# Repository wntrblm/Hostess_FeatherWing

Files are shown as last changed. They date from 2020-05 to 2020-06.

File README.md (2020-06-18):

# Winterbloom Hostess FeatherWing

Picture of the FeatherWing

**:warning: Hostess is *extremely* experimental at this stage. It is not ready for prime time. I welcome folks who want to help out and poke around, but please do not expect anything here to work or make sense. Please reach out to me at me@thea.codes if you're interesting in helping out.**

Hostess is a [FeatherWing](https://learn.adafruit.com/adafruit-feather/featherwings) that provides a USB host co-processor. The FeatherWing handles all USB Host related tasks, including enumeration **and running the device drivers**, and communicates with the primary processor over [SPI](https://learn.adafruit.com/circuitpython-basics-i2c-and-spi/spi-devices). This means the primary processor can communicate with USB devices with minimal software and CPU time.

For example, a [CircuitPython](https://circuitpython.org)-based board could communicate with a USB MIDI device with minimal code:

```python
_spi = busio.SPI(board.SCK, MOSI=board.MOSI, MISO=board.MISO)
spi = SPIDevice(_spi, digitalio.DigitalInOut(board.D9), phase=1, polarity=0, baudrate=8000000)
hostess_midi_in = HostessMidiPortIn(spi)

while True:
    midi_event = hostess_midi_in.read()

    if midi_event is not None:
        print(midi_event)
```

Presently, Hostess has basic support for the following USB devices:

* MIDI
* Keyboard

And in-progress support for the following devices:

* PS4 controller

And I hope to add support for these devices eventually:

* USB Serial (CDC)
* Generic HID Gamepad
* Mouse

## Hardware

Hostess's [hardware](hardware) is based around the [Atmel SAMD21](https://www.microchip.com/wwwproducts/en/ATsamd21g18), a low-cost 32-bit ARM microcontroller with USB host capabilities. It incorporates a USB current-limiting switch to prevent devices from drawing too much current and provides the proper amount of capacitance for powering USB devices. This makes it a bit more robust compared to using an OTG adapter with existing development boards.

Hostess's hardware is the most complete part of the project. PCBs can be manufactured at OSHPark or other fabs and all of the components on the BOM are readily available at Mouser and DigiKey.

To upload the firmware and debug the device, you'll need a [SOICBite](https://github.com/SimonMerrett/SOICbite) and a J-Link or similar.

## Firmware

Hostess's [firmware](firmware) is written in C using [Atmel START](https://start.atmel.com/). Presently building it requires [Atmel Studio 7](https://www.microchip.com/mplab/avr-support/atmel-studio-7), though I'd like to switch to a Makefile.

## Library

Communicating with Hostess is the most incomplete part of the project. Presently, there is just an [example file](library/circuitpython.py) on how to communicate with it from CircuitPython. I'd like to make this a complete library as well as create an Arduino library.

## License and contributing

The code here is available under the [MIT License](firmware/LICENSE), the hardware designs are available under [CC BY-SA 4.0](hardware/LICENSE). I welcome contributors, please read the [Code of Conduct](CODE_OF_CONDUCT.md) first. :)

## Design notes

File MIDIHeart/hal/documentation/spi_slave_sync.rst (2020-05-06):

The SPI Slave Synchronous Driver
================================

The serial peripheral interface (SPI) is a synchronous serial communication
interface.

SPI devices communicate in full duplex mode using a master-slave
architecture with a single master. The slave device uses the control signal
and clocks from master for reading and writing. Slave device is selected through
slave select (SS) line.

When data is read or written through the I/O writing function, the driver keeps
polling until amount of characters achieved. Also it's possible to perform
full-duplex read and write through transfer function, which process read and
write at the same time.

When SS detection is considered, a "break on SS detection" option can be enabled
to make it possible to terminate the read/write/transfer on SS desertion.

Features
--------

* Initialization/de-initialization
* Enabling/disabling
* Control of the following settings:

  * SPI mode
  * Character size
  * Data order
* Data transfer: transmission, reception and full-duplex

Applications
------------

* SPI to I2C bridge that bridges SPI commands to I2C interface.

Dependencies
------------

SPI slave capable hardware

Concurrency
-----------

N/A

Limitations
-----------

N/A

Known issues and workarounds
----------------------------

When writing data through SPI slave, the time that the data appears on data line
depends on the SPI hardware, and previous writing state, since there can be
data in output fifo filled by previous broken transmitting. The number of such
dummy/broken characters is limited by hardware. Whether these dummy/broken
characters can be flushed is also limited by hardware.

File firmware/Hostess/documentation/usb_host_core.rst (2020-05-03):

=============
USB Host Core
=============

USB Host Core is a part of the USB Host Stack library. It handles the hub
changes and issue necessary requests during USB Enumeration process, selects
and installs right class driver to bring up connected devices.
For more detailed description about Bus Enumeration, user can refer to
Chapter 9 (USB Host Framework) in Universal Serial Bus Specification.

The core stack driver is designed to simplify the enumeration of USB device.
After initialization, function drivers can be registered to make corresponding
USB functionalities to be recognizable. After start, the background interrupts
services handles the changes. When USB device is connected, the core
driver will check registered function drivers and enable the right driver(s) to
make the device usable. In this way, multiple registered function drivers can
drive any of the USB device that contains the driver function, or a composite
device that contains multiple compatible functions. Even there is no right
driver found, the device is still accessible so that user can easily customize
the operations.

To avoid dynamically allocation and minimize resources usage in the stack, a
shared control requests processing buffer is required for the stack. The size
of the buffer should be large enough for USB request plus VID and PID (if
supported by configuration) and plus max possible configuration descriptor
total length. The stack core driver use the buffer to process requests and
descriptors for enumeration. When the control resources are not used by core,
it's also possible to be used by user, in that case, the resources will be
taken by user request and released after the request end callback is invoked.

Features
--------

* Initialization/de-initialization
* Devices and functions drivers management
* Suspend/wakeup connected devices
* Callbacks management on:

  * SOF event
  * Connected device state change
  * USB Host request handler

Simplified Usage Flow
---------------------

- Initialization: invoke usbhc_init(), with core driver instance, HAL driver
  instance and allocated control buffer. The initialization code is
  automatically generated by START.
- Register function drivers by invoking usbhc_register_funcd(). Note that even
  there is no function driver for the connected USB device, it still is able to
  be accessed through the core driver, thus allows user to customize the device
  usage.
- Register callbacks to get notified when events happen
- Start USB host stack: invoke usbhc_start()
- Now the stack is running to monitor connection of USB device, status changes
  are reported by callbacks, where user can check the status and raise the
  flags for application to process.

For more detailed descriptions please refer to the APIs.

Practice in START
-----------------

When the component is added into project, a quick example is generated, in
usb_start.c. If the HAL driver and clocks are correctly configured, the example
enumerates the USB device connected to root hub port and read its device
descriptor. To practice you can invoke example routine in your main.c of
generated project, start debugging, connect your USB device and break, you will
find the device descriptor in shared control buffer.

Clock configurations:

- If the hardware supports high-speed and you want that, enable the 480MHz clock
  and make that to be one of your hardware clock source
- If the hardware supports low-speed and full-speed and you want that, enable
  the 48MHz(or 96MHz for some hardware) and make that to be one of your hardware
  clock source

Dependencies
------------

* USB Host Driver
* USB Protocol Core

Limitations
-----------

Currently the driver just enumerates the first device connected to the root hub
port.

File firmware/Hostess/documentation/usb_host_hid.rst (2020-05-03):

==================
USB Host HID Mouse
==================

USB Host HID Mouse is a part of the USB Host Stack library. It provides support
for USB HID Mouse Function driver implementation. It enumerates and handles
inputs from USB HID Mouse function/interface. For more detailed definition and
description about this class, user can refer to
<Device Class Definition for Human Interface Devices (HID), Vision 1.11>.

The driver is registered to the USB Host Core Driver, so that when USB Mouse
Device or USB Composite Device with Mouse Function is connected, it can be
enabled to drive the mouse function.

Features
--------

* Initialization/de-initialization.
* Notifications about button state change for HID Mouse.
* Notifications about mouse move or scroll for HID Mouse.

Applications
------------

* Detect and operate on a HID Mouse.

Dependencies
------------

* USB Host Driver
* USB Host Stack Core
* USB Protocol HID

Limitations
-----------

N/A

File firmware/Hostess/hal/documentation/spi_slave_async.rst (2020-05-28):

The SPI Slave Asynchronous Driver
=================================

The serial peripheral interface (SPI) is a synchronous serial communication
interface.

SPI devices communicate in full duplex mode using a master-slave
architecture with a single master. The slave device uses the control signal
and clocks from master for reading and writing. Slave device is selected through
slave select (SS) line.

When data is written through the I/O writing function, the data buffer pointer
and its size is logged internally by the driver. The data is sent character by
character in background interrupts. When all data in the buffer is sent,
callback is invoked to notify that it's done.

When the driver is enabled, the characters shifted in will be filled to a
receiving ring-buffer, then the available data can be read out through the I/O
reading function. On each characters' reception a callback is invoked.

In some cases, the SS deactivation is considered, it's notified through a
completion callback with status code zero. When status code is lower than zero,
it indicates error.

Features
--------

* Initialization/de-initialization
* Enabling/disabling
* Control of the following settings:

  * SPI mode
  * Character size
  * Data order
* Data transfer: transmission, reception and full-duplex
* Callbacks management on:

  * Transmission done
  * Received character
  * Completion by SS detection or error

Applications
------------

* SPI to I2C bridge that bridges SPI commands to I2C interface.
* SPI WIFI module

Dependencies
------------

SPI slave capable hardware

Concurrency
-----------

N/A

Limitations
-----------

When received data is not read promptly, the ring-buffer is used out. In this
case the oldest characters will be overwritten by the newest ones.

Known issues and workarounds
----------------------------

When writing data through SPI slave, the time that the data appears on data line
depends on the SPI hardware, and previous writing state, since there can be
data in output fifo filled by previous broken transmitting. The number of such
dummy/broken characters is limited by hardware. Whether these dummy/broken
characters can be flushed is also limited by hardware.

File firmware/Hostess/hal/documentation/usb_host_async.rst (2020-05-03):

The USB Host Asynchronous Driver
==================================

Universal Serial Bus (USB) is an industry standard that defines the cables,
connectors and communication protocols used in a bus for connection,
communication, and power supply between computers and electronic devices.

The USB host driver provides necessary APIs to support USB states and
USB data flow. So that the USB Device enumeration, class and vendor support can
be implemented base on it. The driver is asynchronous, which means that all USB
data processing is done in callbacks.

To recognized a device, a USB host must handle a subset of the USB events. The
USB host should turn on VBus supply, monitor root hub events, build up control
communication to request descriptors of attached device. An application or upper
stack that uses the USB host driver should have its descriptors buffer prepared,
issue the control requests, analyze the returned descriptors and handle them
correctly.

Usually, a USB host application that can enumerates USB device may use the
following sequence:

* Initialize
* Register callback and handle root hub events, where:

  * On connection, issue USB Reset
  * On USB Reset end, initialize pipe 0, register request end callback
    and issue *GetDeviceDescriptor* request
  * On disconnection, free all allocated pipes

* In pipe 0 request done handling callback:

  * On *GetDeviceDescriptor* OK, modify pipe 0 endpoint size according to the
    descriptor returned, issue *SetAddress* request
  * On *SetAddress* request OK, issue *GetConfigurationDescriptor* request
  * On *GetConfigurationDescriptor* request OK, create pipes based on returned
    configuration descriptor; issue *SetConfigure* request

* Enable
* After the *SetConfigure* request is done correctly, the created pipes should
  be OK to communicate with the USB device

Features
--------

* Initialization/de-initialization
* Enabling/disabling
* USB root hub control

  * Attach/detach detection
  * Reset
  * Suspend/resume
  * Connection speed detection
* USB host frame number and micro frame number status
* Callback management for:

  * Start of Frame (SOF)
  * Root hub events
* Pipes management:

  * Pipe allocation/free
  * Control pipe request
  * Bulk, interrupt and ISO pipe transfer
  * Pipe callback management for transfer done

Applications
------------

USB Host stack, to manage root hub, issue control requests and process
data.

Dependencies
------------

* USB host capable hardware
* 48MHz clock for low-speed and full-speed and 480MHz clock for high-speed

Concurrency
-----------

N/A

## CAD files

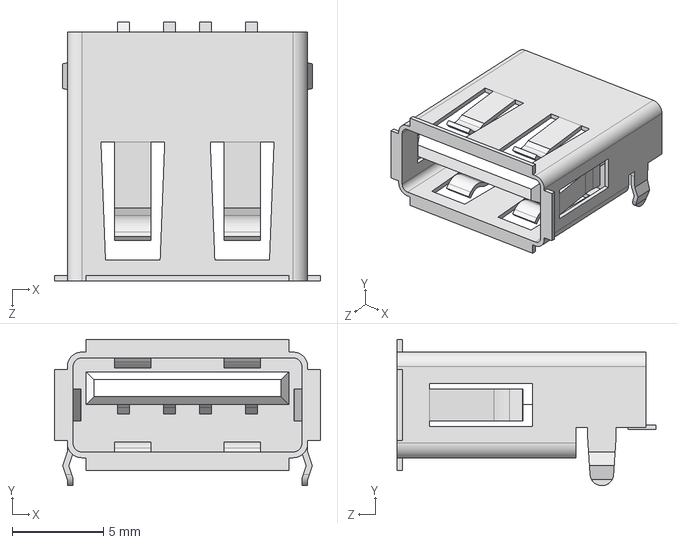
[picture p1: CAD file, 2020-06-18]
hardware/3dmodels/USB-A-Socket.step
14.6 x 8.03 x 14.2 mm

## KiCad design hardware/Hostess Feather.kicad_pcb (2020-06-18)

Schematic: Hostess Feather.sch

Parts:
C1: 1uF; C_0805_2012Metric_Pad1.15x1.40mm_HandSolder; mpn MF-CAP-0805-1uF
C2, C3, C4, C8: 0.1uF; C_0805_2012Metric_Pad1.15x1.40mm_HandSolder; mpn MF-CAP-0805-0.1uF
C5, C6: 22pF; C_0805_2012Metric_Pad1.15x1.40mm_HandSolder; mpn MF-CAP-0603-22pF
C7: 100uF; C_1206_3216Metric_Pad1.42x1.75mm_HandSolder; mpn GRM31CR61A107ME05L
D1: Connected; LED_0805_2012Metric_Pad1.15x1.40mm_HandSolder; mpn MF-LED-0805-GREEN
D2: Read; LED_0805_2012Metric_Pad1.15x1.40mm_HandSolder; mpn MF-LED-0805-GREEN
D3: Write; LED_0805_2012Metric_Pad1.15x1.40mm_HandSolder; mpn MF-LED-0805-RED
J1: USB_A; USB_A_Stewart_SS-52100-001_Horizontal; mpn SS-52100-001
J2: CON_01X16_PTH_2.54MM; MF_Connectors-PTH_2.54MM_01X16
J3: CON_01X12_PTH_2.54MM; MF_Connectors-PTH_2.54MM_01X12
J4: SOICBite; SOIC_clipProgSmall
JP1, JP2, JP5, JP6, JP7: SolderJumper_2_Open; SolderJumper-2_P1.3mm_Open_TrianglePad1.0x1.5mm
JP3, JP4: SolderJumper_2_Bridged; SolderJumper-2_P1.3mm_Bridged_Pad1.0x1.5mm
R1, R2, R3: 1k; R_0805_2012Metric_Pad1.15x1.40mm_HandSolder; mpn MF-RES-0805-1K
U1: ATSAMD21G18A-AUT; TQFP-48_7x7mm_P0.5mm; mpn ATSAMD21G18A-AUT
U2: TPS2051CDBV; SOT-23-5_HandSoldering; mpn TPS2051CDBV
Y1: Crystal; Crystal_SMD_2012-2Pin_2.0x1.2mm_HandSoldering; mpn ABS06-32.768KHz-1-T

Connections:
+3V3: C1.1, C2.1, C3.1, C4.1, J2.2 (PIN2), J4.1, U1.6 (VDDANA), U1.17 (VDDIO), U1.36 (VDDIO), U1.44 (VDDIN)
CONNECTED_LED: R1.1, U1.4 (PA03)
D5: J3.10 (PIN10), JP1.1 (A)
D6: J3.9 (PIN9), JP2.1 (A)
D9: J3.8 (PIN8), JP3.1 (A)
D10: J3.7 (PIN7), JP4.1 (A)
D11: J3.6 (PIN6), JP5.1 (A)
D12: J3.5 (PIN5), JP6.1 (A)
D13: J3.4 (PIN4)
D+: J1.3 (D+), U1.34 (PA25)
D-: J1.2 (D-), U1.33 (PA24)
FAULT: U1.25 (PA16), U2.3
GND: C2.2, C3.2, C4.2, C5.2, C6.2, C7.2, C8.2, D1.1 (K), D2.1 (K), D3.1 (K), J1.4 (GND), J1.5 (Shield), J2.4 (PIN4), J2.16 (PIN16), J4.4, U1.5 (GNDANA), U1.18 (GND), U1.35 (GND), U1.42 (GND), U2.2
MISO: J2.13 (PIN13), U1.21 (PA12)
MOSI: J2.12 (PIN12), U1.19 (PB10)
unnamed: C1.2, U1.43 (VDDCORE)
unnamed: D1.2 (A), R1.2
unnamed: D2.2 (A), R2.2
unnamed: D3.2 (A), R3.2
READ_LED: R2.1, U1.10 (PA05)
RESET: J4.8, JP2.2 (B), JP4.2 (B), JP6.2 (B), U1.40 (~RESET)
RX: J4.2, U1.16 (PA11)
SCK: J2.11 (PIN11), U1.20 (PB11)
SS: JP1.2 (B), JP3.2 (B), JP5.2 (B), U1.8 (PB09)
SWCLK: J4.7, U1.45 (PA30)
SWDIO: J4.5, U1.46 (PA31)
TX: J4.3, U1.15 (PA10)
VBUSEN: U1.24 (PA15), U2.4
VBUS_FILTERED: C7.1, C8.1, J1.1 (VBUS), JP7.1 (A), U2.1
VUSB: J3.3 (PIN3), JP7.2 (B), U2.5
WRITE_LED: R3.1, U1.12 (PA07)
XIN: C5.1, U1.1 (PA00), Y1.1
XOUT: C6.1, U1.2 (PA01), Y1.2

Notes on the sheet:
Blue
Green
Yellow or Red
Possible future enhancement: ESD (USBLC6)

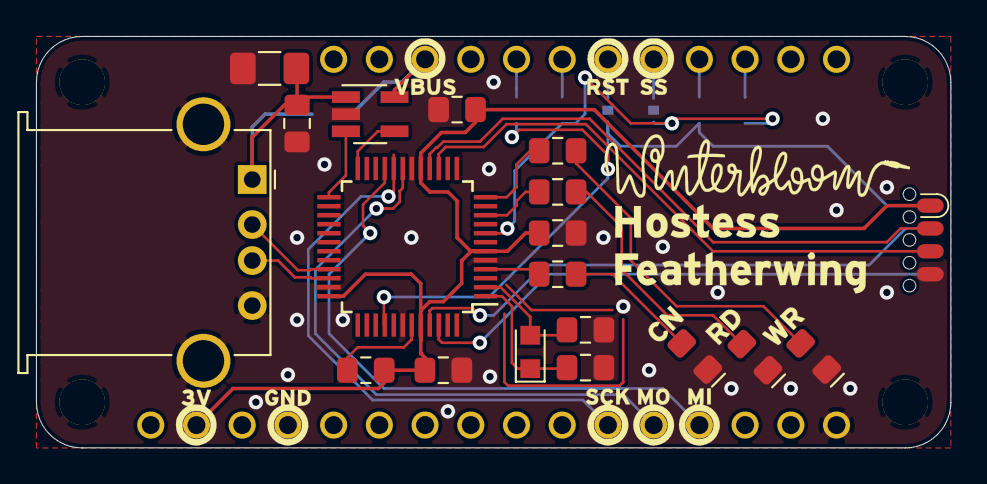
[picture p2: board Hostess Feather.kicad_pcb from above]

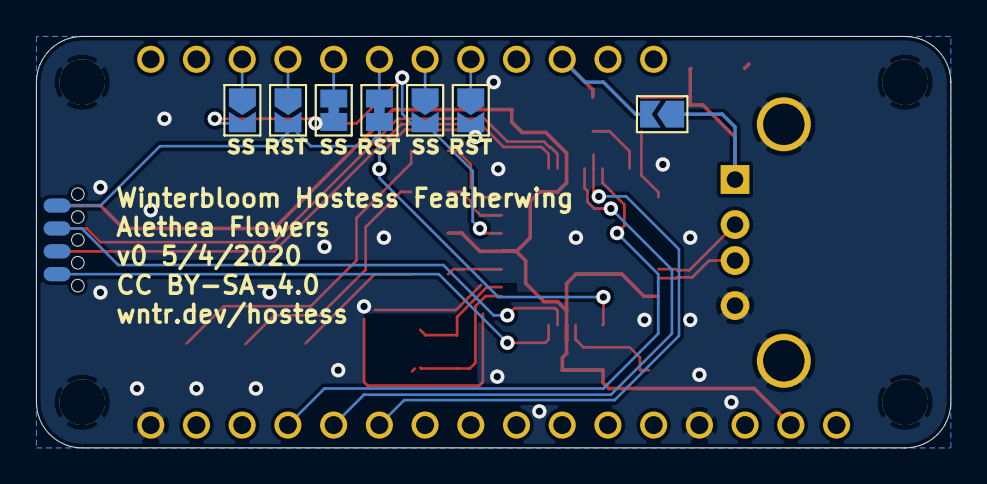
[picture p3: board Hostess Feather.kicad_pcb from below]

Board: 2 copper layers, 50.8 x 22.9 mm, 29 parts (7 on the bottom side), 32 nets.

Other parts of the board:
Ref**: Val**; decal

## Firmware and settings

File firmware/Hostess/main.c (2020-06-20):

#include <atmel_start.h>
#include <hpl_delay.h>

#include "wtr_spi_dma.h"
#include "wtr_hid_keyboard_host_driver.h"
#include "wtr_midi_host_driver.h"
#include "wtr_ps4_host_driver.h"
#include "wtr_queue.h"
#include "wtr_usb_host.h"
#include "hostess_status_leds.h"
#include "hostess_command_processor.h"


/* USB wiring to control the current-limit switch and connection LED */

static hal_atomic_t vbus_fault_atomic;

void vbus_control(bool enable) {
    gpio_set_pin_level(VUSB_EN_PIN, enable);
    if(!enable) {
        hostess_flash_led(HTS_STATUS_LED_CONNECTION);
    }
}

void vbus_fault_interrupt() {
    atomic_enter_critical(&vbus_fault_atomic);
    vbus_control(false);
    atomic_leave_critical(&vbus_fault_atomic);
}

void usb_connection_callback(uint8_t port, bool state) {
    hostess_set_led(HTS_STATUS_LED_CONNECTION, state);
}


/* SPI wiring to connect SPI to the Hostess command parser. */
/*
Some notes about this code: instead of using the standard Atmel
SPI write logic, this uses wtr_spi_dma_write to configure a
DMA transaction. All bytes received from the host are ignored
until the DMA is complete.

I considered using DMA for the read side, too, but it's a lot
of work for little gain, considering most requests take 2 bytes
and they need to be parsed by this code anyway.
*/

struct wtr_spi_dma_inst dma_spi;

static int32_t spi_dma_io_write_adapter(struct io_descriptor *const io, const uint8_t *const buf, const uint16_t size) {
    return wtr_spi_dma_write(&dma_spi, (uint8_t *)buf, size);
}

void spi_rx_callback(const struct spi_s_async_descriptor *const spi_desc) {
    struct io_descriptor *io;
    spi_s_async_get_io_descriptor(&SPI_0, &io);

    // Replace the write function with the DMA-enabled write function.
    io->write = &spi_dma_io_write_adapter;

    hostess_parse_byte_stream(io);
}



int main(void) {
    // Initializes MCU, drivers and middleware
    atmel_start_init();

    // Set interrupt priorities. The SPI interrupt should
    // be serviced as quickly as possible to prevent
    // the host from timing out.
    NVIC_SetPriority(SERCOM4_IRQn,0);
    NVIC_SetPriority(USB_IRQn, 1);
    NVIC_SetPriority(RTC_IRQn, 3);

    // Start the LED driver.
    hostess_leds_init(&TIMER_0);
    timer_start(&TIMER_0);

    // Start the USB host
    wtr_usb_host_set_connection_callback(&usb_connection_callback);
    wtr_usb_host_init(&USB_0_inst);

    // Enable USB Host Drivers.
    wtr_usb_midi_init();
    wtr_usb_hid_keyboard_init();
    //wtr_ps4_controller_init();
    
    // Setup the vbus fault interrupt.
    ext_irq_register(VBUS_FAULT_PIN, &vbus_fault_interrupt);

    // Enable VBUS power.
    vbus_control(true);

    // Grab event queues from host drivers and wire them up to
    // the hostess command processor.
    hostess_set_queue(HOSTESS_QUEUE_MIDI_IN, wtr_usb_midi_get_in_queue());
    hostess_set_queue(HOSTESS_QUEUE_MIDI_OUT, wtr_usb_midi_get_out_queue());
    hostess_set_queue(HOSTESS_QUEUE_KB_EVENT, wtr_usb_hid_keyboard_get_event_queue());
    hostess_set_queue(HOSTESS_QUEUE_KB_STRING, wtr_usb_hid_keyboard_get_keystring_queue());

    // Configure SPI DMA
    _dma_init();
    dma_spi.dma_channel = 1;
    dma_spi.sercom = SERCOM4;

    // Start listening for SPI.
    spi_s_async_register_callback(&SPI_0, SPI_S_CB_RX, (FUNC_PTR)spi_rx_callback);
    spi_s_async_enable(&SPI_0);

    while (1) {
    }
}

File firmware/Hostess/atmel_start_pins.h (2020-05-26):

/*
 * Code generated from Atmel Start.
 *
 * This file will be overwritten when reconfiguring your Atmel Start project.
 * Please copy examples or other code you want to keep to a separate file
 * to avoid losing it when reconfiguring.
 */
#ifndef ATMEL_START_PINS_H_INCLUDED
#define ATMEL_START_PINS_H_INCLUDED

#include <hal_gpio.h>

// SAMD21 has 8 pin functions

#define GPIO_PIN_FUNCTION_A 0
#define GPIO_PIN_FUNCTION_B 1
#define GPIO_PIN_FUNCTION_C 2
#define GPIO_PIN_FUNCTION_D 3
#define GPIO_PIN_FUNCTION_E 4
#define GPIO_PIN_FUNCTION_F 5
#define GPIO_PIN_FUNCTION_G 6
#define GPIO_PIN_FUNCTION_H 7

#define CONNECTED_LED_PIN GPIO(GPIO_PORTA, 3)
#define READ_LED_PIN GPIO(GPIO_PORTA, 5)
#define WRITE_LED_PIN GPIO(GPIO_PORTA, 7)
#define PA10 GPIO(GPIO_PORTA, 10)
#define PA11 GPIO(GPIO_PORTA, 11)
#define PA12 GPIO(GPIO_PORTA, 12)
#define VUSB_EN_PIN GPIO(GPIO_PORTA, 15)
#define VBUS_FAULT_PIN GPIO(GPIO_PORTA, 16)
#define LED GPIO(GPIO_PORTA, 17)
#define PA24 GPIO(GPIO_PORTA, 24)
#define PA25 GPIO(GPIO_PORTA, 25)
#define PB09 GPIO(GPIO_PORTB, 9)
#define PB10 GPIO(GPIO_PORTB, 10)
#define PB11 GPIO(GPIO_PORTB, 11)

#endif // ATMEL_START_PINS_H_INCLUDED

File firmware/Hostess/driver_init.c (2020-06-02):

/*
 * Code generated from Atmel Start.
 *
 * This file will be overwritten when reconfiguring your Atmel Start project.
 * Please copy examples or other code you want to keep to a separate file
 * to avoid losing it when reconfiguring.
 */

#include "driver_init.h"
#include <peripheral_clk_config.h>
#include <utils.h>
#include <hal_init.h>
#include <hpl_gclk_base.h>
#include <hpl_pm_base.h>

#include <hpl_rtc_base.h>

struct timer_descriptor TIMER_0;

struct usart_sync_descriptor TARGET_IO;

struct spi_s_async_descriptor SPI_0;
static uint16_t               SPI_0_buf[16];

struct usb_h_desc USB_0_inst;

void EXTERNAL_IRQ_0_init(void)
{
	_gclk_enable_channel(EIC_GCLK_ID, CONF_GCLK_EIC_SRC);

	// Set pin direction to input
	gpio_set_pin_direction(VBUS_FAULT_PIN, GPIO_DIRECTION_IN);

	gpio_set_pin_pull_mode(VBUS_FAULT_PIN,
	                       // <y> Pull configuration
	                       // <id> pad_pull_config
	                       // <GPIO_PULL_OFF"> Off
	                       // <GPIO_PULL_UP"> Pull-up
	                       // <GPIO_PULL_DOWN"> Pull-down
	                       GPIO_PULL_UP);

	gpio_set_pin_function(VBUS_FAULT_PIN, PINMUX_PA16A_EIC_EXTINT0);

	ext_irq_init();
}

void TARGET_IO_PORT_init(void)
{

	gpio_set_pin_function(PA10, PINMUX_PA10C_SERCOM0_PAD2);

	gpio_set_pin_function(PA11, PINMUX_PA11C_SERCOM0_PAD3);
}

void TARGET_IO_CLOCK_init(void)
{
	_pm_enable_bus_clock(PM_BUS_APBC, SERCOM0);
	_gclk_enable_channel(SERCOM0_GCLK_ID_CORE, CONF_GCLK_SERCOM0_CORE_SRC);
}

void TARGET_IO_init(void)
{
	TARGET_IO_CLOCK_init();
	usart_sync_init(&TARGET_IO, SERCOM0, (void *)NULL);
	TARGET_IO_PORT_init();
}

void SPI_0_PORT_init(void)
{

	gpio_set_pin_level(PA12,
	                   // <y> Initial level
	                   // <id> pad_initial_level
	                   // <false"> Low
	                   // <true"> High
	                   false);

	// Set pin direction to output
	gpio_set_pin_direction(PA12, GPIO_DIRECTION_OUT);

	gpio_set_pin_function(PA12, PINMUX_PA12D_SERCOM4_PAD0);

	// Set pin direction to input
	gpio_set_pin_direction(PB09, GPIO_DIRECTION_IN);

	gpio_set_pin_pull_mode(PB09,
	                       // <y> Pull configuration
	                       // <id> pad_pull_config
	                       // <GPIO_PULL_OFF"> Off
	                       // <GPIO_PULL_UP"> Pull-up
	                       // <GPIO_PULL_DOWN"> Pull-down
	                       GPIO_PULL_OFF);

	gpio_set_pin_function(PB09, PINMUX_PB09D_SERCOM4_PAD1);

	// Set pin direction to input
	gpio_set_pin_direction(PB10, GPIO_DIRECTION_IN);

	gpio_set_pin_pull_mode(PB10,
	                       // <y> Pull configuration
	                       // <id> pad_pull_config
	                       // <GPIO_PULL_OFF"> Off
	                       // <GPIO_PULL_UP"> Pull-up
	                       // <GPIO_PULL_DOWN"> Pull-down
	                       GPIO_PULL_OFF);

	gpio_set_pin_function(PB10, PINMUX_PB10D_SERCOM4_PAD2);

	gpio_set_pin_level(PB11,
	                   // <y> Initial level
	                   // <id> pad_initial_level
	                   // <false"> Low
	                   // <true"> High
	                   false);

	// Set pin direction to output
	gpio_set_pin_direction(PB11, GPIO_DIRECTION_OUT);

	gpio_set_pin_function(PB11, PINMUX_PB11D_SERCOM4_PAD3);
}

void SPI_0_CLOCK_init(void)
{
	_pm_enable_bus_clock(PM_BUS_APBC, SERCOM4);
	_gclk_enable_channel(SERCOM4_GCLK_ID_CORE, CONF_GCLK_SERCOM4_CORE_SRC);
}

void SPI_0_init(void)
{
	SPI_0_CLOCK_init();
	spi_s_async_init(&SPI_0, SERCOM4, (uint8_t *)SPI_0_buf, 32);
	SPI_0_PORT_init();
}

void delay_driver_init(void)
{
	delay_init(SysTick);
}

/**
 * \brief Timer initialization function
 *
 * Enables Timer peripheral, clocks and initializes Timer driver
 */
static void TIMER_0_init(void)
{
	_pm_enable_bus_clock(PM_BUS_APBA, RTC);
	_gclk_enable_channel(RTC_GCLK_ID, CONF_GCLK_RTC_SRC);
	timer_init(&TIMER_0, RTC, _rtc_get_timer());
}

/* The USB module requires a GCLK_USB of 48 MHz ~ 0.25% clock
 * for low speed and full speed operation. */
#if (CONF_GCLK_USB_FREQUENCY > (48000000 + 48000000 / 400)) || (CONF_GCLK_USB_FREQUENCY < (48000000 - 48000000 / 400))
#warning USB clock should be 48MHz ~ 0.25% clock, check your configuration!
#endif

/** \brief VBus control callback
 *  VBus must be always turned on if this callback is disabled.
 */
WEAK void my_vbus_ctrl_func(void *drv, uint8_t port, bool onoff)
{
	/* Turn on/off your root hub port power */
}

void USB_0_CLOCK_init(void)
{

	_pm_enable_bus_clock(PM_BUS_APBB, USB);
	_pm_enable_bus_clock(PM_BUS_AHB, USB);
	_gclk_enable_channel(USB_GCLK_ID, CONF_GCLK_USB_SRC);
}

void USB_0_PORT_init(void)
{

	gpio_set_pin_direction(PA24,
	                       // <y> Pin direction
	                       // <id> pad_direction
	                       // <GPIO_DIRECTION_OFF"> Off
	                       // <GPIO_DIRECTION_IN"> In
	                       // <GPIO_DIRECTION_OUT"> Out
	                       GPIO_DIRECTION_OUT);

	gpio_set_pin_level(PA24,
	                   // <y> Initial level
	                   // <id> pad_initial_level
	                   // <false"> Low
	                   // <true"> High
	                   false);

	gpio_set_pin_pull_mode(PA24,
	                       // <y> Pull configuration
	                       // <id> pad_pull_config
	                       // <GPIO_PULL_OFF"> Off
	                       // <GPIO_PULL_UP"> Pull-up
	                       // <GPIO_PULL_DOWN"> Pull-down
	                       GPIO_PULL_OFF);

	gpio_set_pin_function(PA24,
	                      // <y> Pin function
	                      // <id> pad_function
	                      // <i> Auto : use driver pinmux if signal is imported by driver, else turn off function
	                      // <PINMUX_PA24G_USB_DM"> Auto
	                      // <GPIO_PIN_FUNCTION_OFF"> Off
	                      // <GPIO_PIN_FUNCTION_A"> A
	                      // <GPIO_PIN_FUNCTION_B"> B
	                      // <GPIO_PIN_FUNCTION_C"> C
	                      // <GPIO_PIN_FUNCTION_D"> D
	                      // <GPIO_PIN_FUNCTION_E"> E
	                      // <GPIO_PIN_FUNCTION_F"> F
	                      // <GPIO_PIN_FUNCTION_G"> G
	                      // <GPIO_PIN_FUNCTION_H"> H
	                      PINMUX_PA24G_USB_DM);

	gpio_set_pin_direction(PA25,
	                       // <y> Pin direction
	                       // <id> pad_direction
	                       // <GPIO_DIRECTION_OFF"> Off
	                       // <GPIO_DIRECTION_IN"> In
	                       // <GPIO_DIRECTION_OUT"> Out
	                       GPIO_DIRECTION_OUT);

	gpio_set_pin_level(PA25,
	                   // <y> Initial level
	                   // <id> pad_initial_level
	                   // <false"> Low
	                   // <true"> High
	                   false);
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

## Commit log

2020-05-03 Initial version
    Basic working USB Midi host that re-transmit MIDI events over UART serial.
    No error handling yet.
    [atmel_start_pins.h, driver_examples.c]
2020-05-03 Add spi slave from Atmel Start
2020-05-06 Basic SPI slave MIDI events working
2020-05-06 Add basic handling of device disconnection
2020-05-06 Single driver assignment
2020-05-08 Add basic SPI Command set
2020-05-09 Basic HID driver, no parsing yet
2020-05-11 Add SPI commands for getting the keystring
2020-05-11 Make keyboard driver properly poll using the endpoint interval
2020-05-26 Add pins for LEDs and current-limit switch on v0 hardware
2020-05-26 Make connected LED work
2020-05-26 Get read led to work
2020-05-28 Add hostess_status_leds to manage LED states
2020-05-28 Add startup LED animation
2020-05-28 Fix some small bugs with the LED animation
    [hostess_status_leds.c]
2020-05-28 Switch to async SPI
2020-05-29 Add start of frame callbacks for host drivers
2020-05-31 Make the midi in poll re-schedule itself, rather than doing it every frame
2020-06-01 * Disable interrupts during the SPI response procedure. * Raise the nack limit for MIDI in, since it was way too low. * Add MIDI debug for the time being to debug dropped messages/stuck keys.
    [main.c]
2020-06-02 Add external interrupt controller
2020-06-03 Don't prevent setting LED state during the startup animation
    [hostess_status_leds.c]
2020-06-03 Fix a comment style
    [main.c]
2020-06-05 Add unfinished PS4 controller driver
2020-06-08 Change SPI slow clock
2020-06-08 Add wtr_debug to easily disable printf throughout
2020-06-09 Got DMA working for the first time
2020-06-18 Stat moving spi dma stuff into wtr_spi_dma
2020-06-18 Add hardware
    [Hostess Feather.kicad_pcb, Hostess Feather.sch, USB-A-Socket.step]
2020-06-18 Add CircuitPython example
2020-06-20 The DMA hack shall remain
2020-06-20 Fixup some function names to be more consistent
    [main.c]
2020-06-20 Fix interrupt priority
